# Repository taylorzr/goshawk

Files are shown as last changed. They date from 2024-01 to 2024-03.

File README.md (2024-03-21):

# goshawk

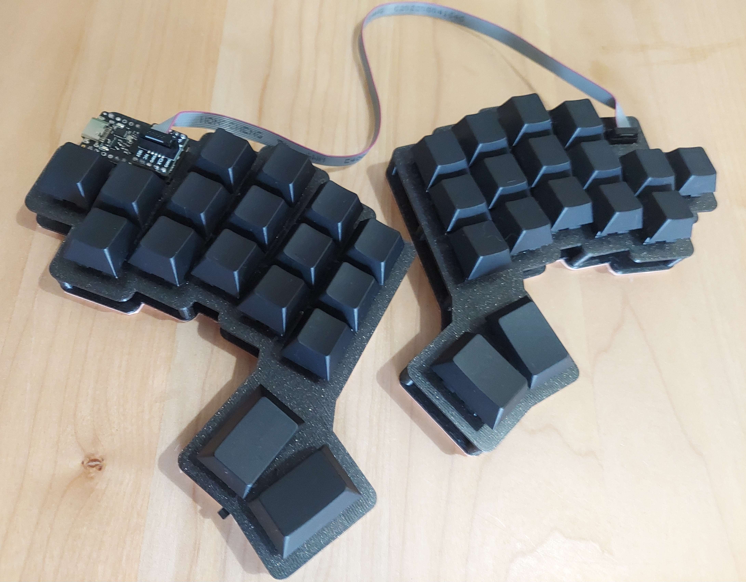
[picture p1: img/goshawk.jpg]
goshawk


wireless keyboard with distintive features rarely seen elsewhere

* split design, but only requires 1 controller/battery
* 8 physical rows mapped to 4 logical rows makes it easier to wire

splay and key layout inspired by [osprette](https://github.com/smores56/osprette) / [clog](https://github.com/smores56/clog-v2) and [lil chonky bois](https://github.com/sanderboer/chonkybois)

split inspired by [schrodinger](https://www.reddit.com/r/MechanicalKeyboards/comments/yrse5t/the_schrodinger_a_keyboard_thats_both_wired_and/)

## bom

| Syntax | Quantity | Link |
| --- | --- | ---- |
| nice-nano | 1 | https://nicekeyboards.com/nice-nano/#find-a-store |
| battery | 1 | 601230 |
| idc cable board | 2 | https://www.adafruit.com/product/2743 |
| idc cable | 1 | https://www.adafruit.com/product/5804 |
| power switch | 1 | https://www.amazon.com/dp/B09R3ZWBBC |

## build

see [build.md](./build.md)

## pinout

8 physical rows mapped to 4 logical rows. Rows 1-4 are left side, rows 5-8 are right side.

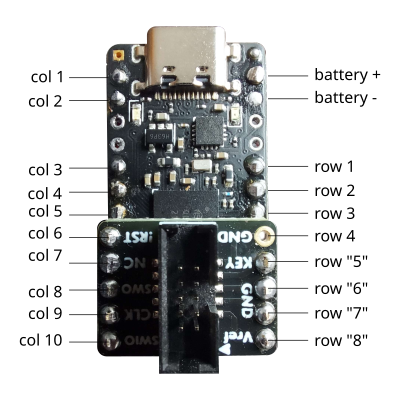
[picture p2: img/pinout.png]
pinout


## zmk config

https://github.com/taylorzr/zmk-config/tree/master/config/boards/shields/goshawk

## 3d model

https://cad.onshape.com/documents/b1a3d5d385ce946f6e9b2f83/w/2e8ce54f087bb732d581ef47/e/49486961fd79efcfe6401002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

## v1 -> v2

problems with v1
- pins are fragile
- fitting pins into bottom is finicky
  - i printed at same size, and then lightly drilled out the holes, but it was difficult to get
    consistent tension
- spacing between columns felt slightly too large
- pinky column drop was slightly too small

v2 changes
- added perimeter wall and slight chamfer
- m3 screws instead of pins
  - M3 x D5 x L4.0 (same as lil chonky bois)
  - https://www.amazon.com/uxcell-Knurled-Insert-Female-Embedding/dp/B09MCW7ZN5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
- adjusting column and pinky spacing
- no interior supports
  - with the perimeter wall, I don't feel like the top plate is too weak

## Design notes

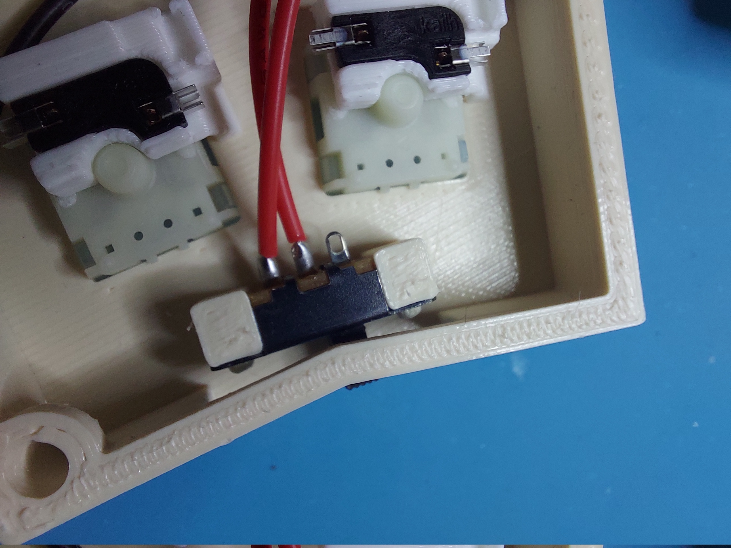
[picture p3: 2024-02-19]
img/power_switch.jpg

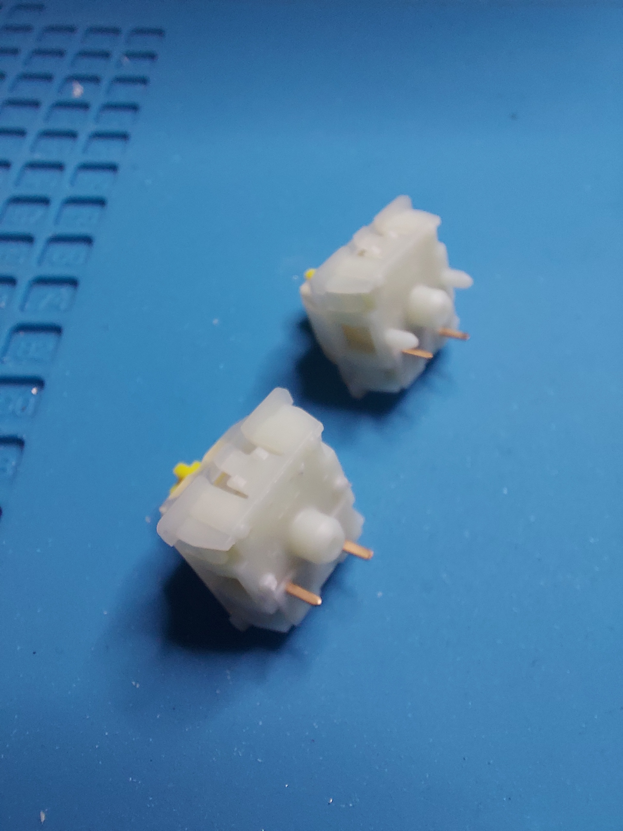
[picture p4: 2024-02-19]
img/remove_switch_pegs.jpg

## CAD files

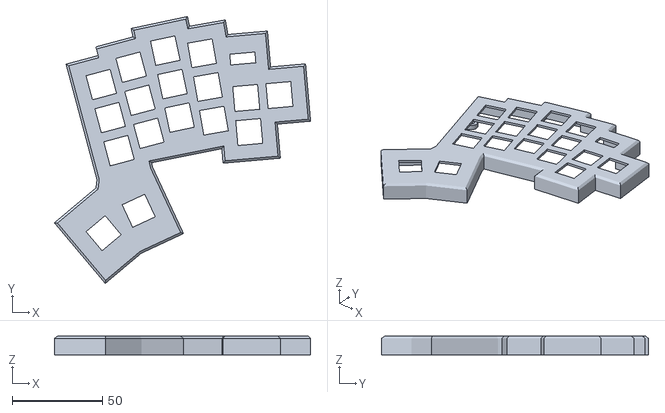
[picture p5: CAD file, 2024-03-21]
case/goshawk v2.1 - right.stl
142.4 x 148.3 x 10.4

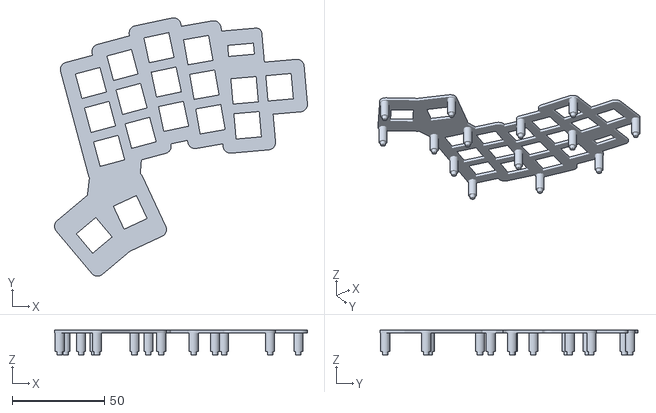
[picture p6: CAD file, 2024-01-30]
case/v1/right.stl
136.9 x 139.8 x 13.5

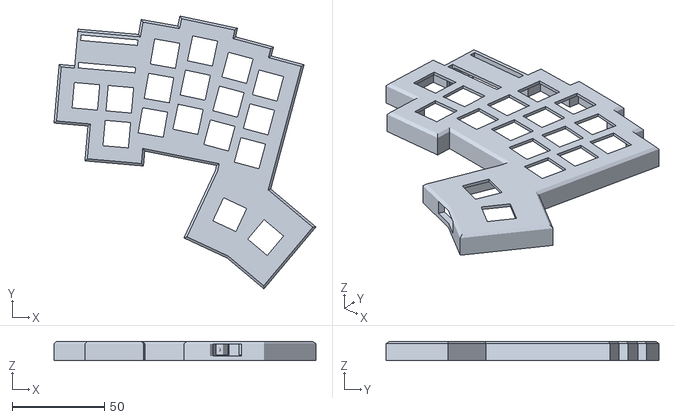
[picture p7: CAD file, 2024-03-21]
case/goshawk v2.1 - left.stl
142.4 x 148.3 x 10.4

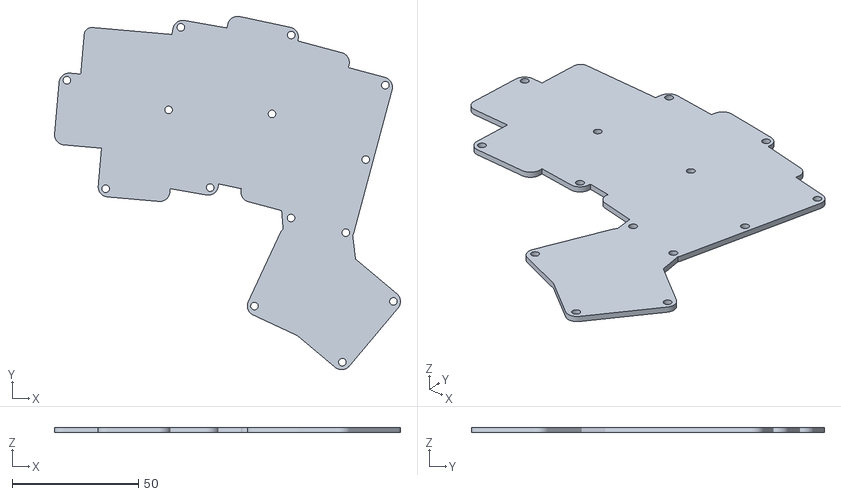
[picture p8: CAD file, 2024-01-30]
case/v1/left bottom.stl
136.9 x 139.8 x 2.00

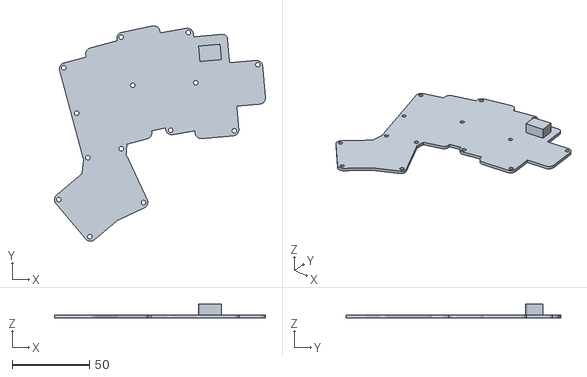
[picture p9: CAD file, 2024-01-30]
case/v1/right bottom.stl
136.9 x 139.8 x 9.00

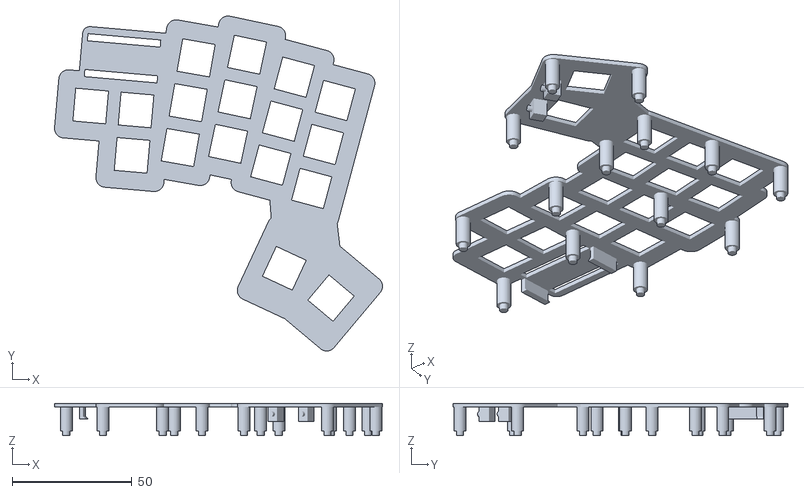
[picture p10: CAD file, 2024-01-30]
case/v1/left.stl
136.9 x 139.8 x 13.5

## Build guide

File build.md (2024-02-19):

# goshawk build guide

## Wiring left half

### icd board -> microcontroller

Solder headers onto the idc board. And then solder idc board to bottom of the microcontroller.

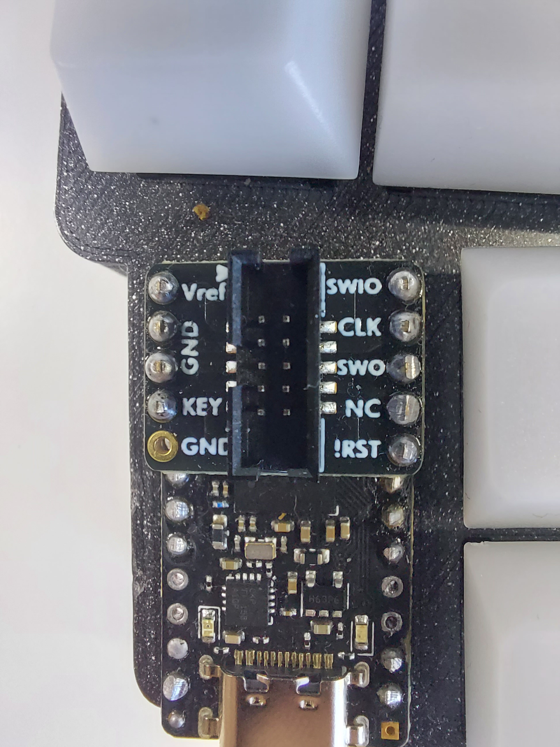
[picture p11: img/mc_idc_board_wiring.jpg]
mc_idc_board_wiring


The important part is the bottom left of the idc board should be left open. The pin is labeled GND on
the idc board. And on the microcontroller, this will be D18.

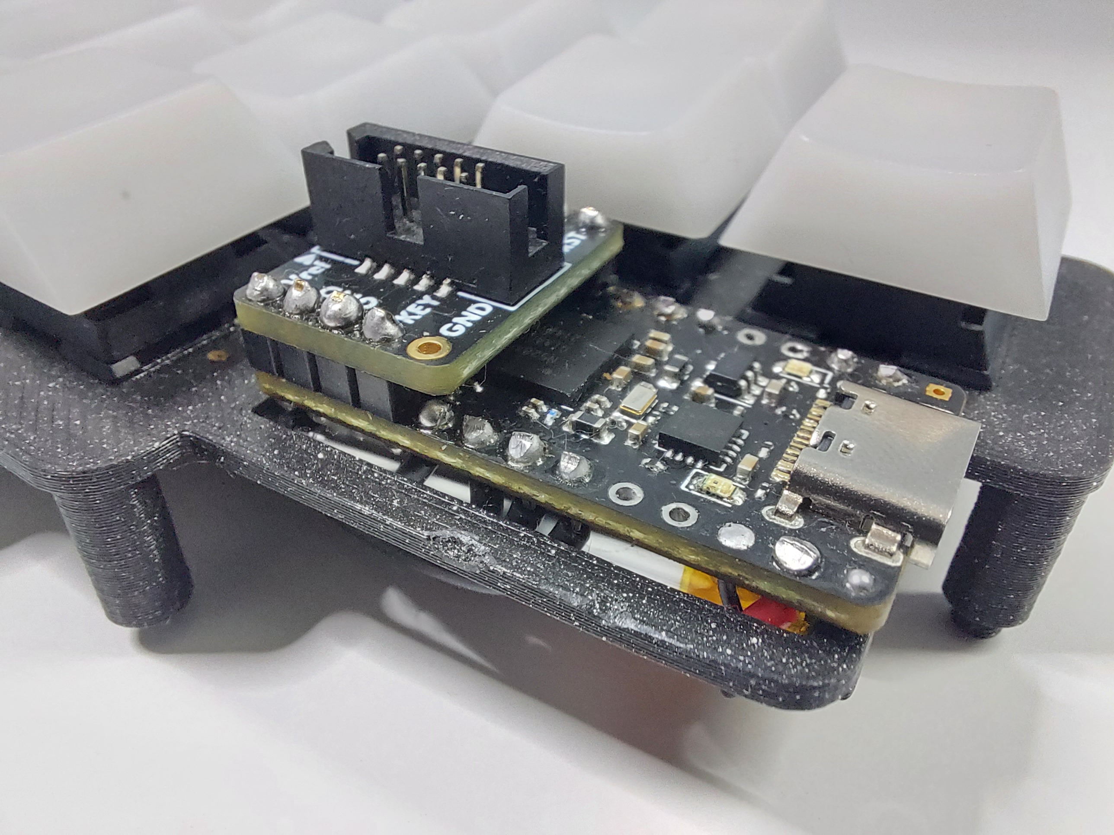
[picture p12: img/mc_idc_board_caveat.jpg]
mc_idc_board_caveat


### microcontroller wiring

Solder wires to the microcontroller. Make sure you leave them long enough to reach the rows,
columns, and power switch.

microcontroller_wiring

### microcontroller and battery installation

Pass microcontroller wiring through the case. Insert the battery, and solder the batteries black cable to microcontroller GND.

To attach the microcontroller to the case. I just use a command hook sticker. Cut it to size and slide it into place using a tweezer. Line up everything and squish.

mc_battery_install

### wire routing

Can run this however you want, but I've found you can get very clean wiring if you route the wires before soldering the matrix. This is a photo of the right side, but same process, route wires for columns, and for row 4.

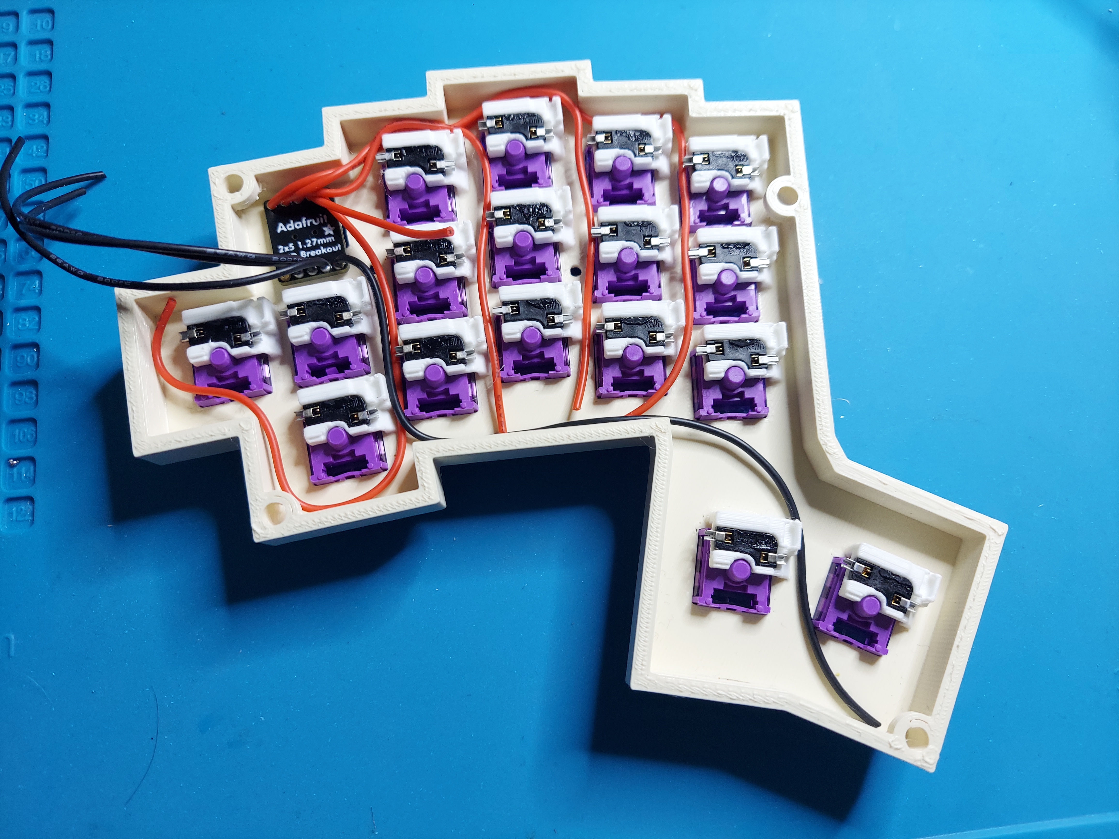
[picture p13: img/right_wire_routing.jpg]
right_wire_routing


### solder matrix

Solder colums first, then rows with diodes.

Batteries red cable, and the top right red cable get soldered to the power switch.

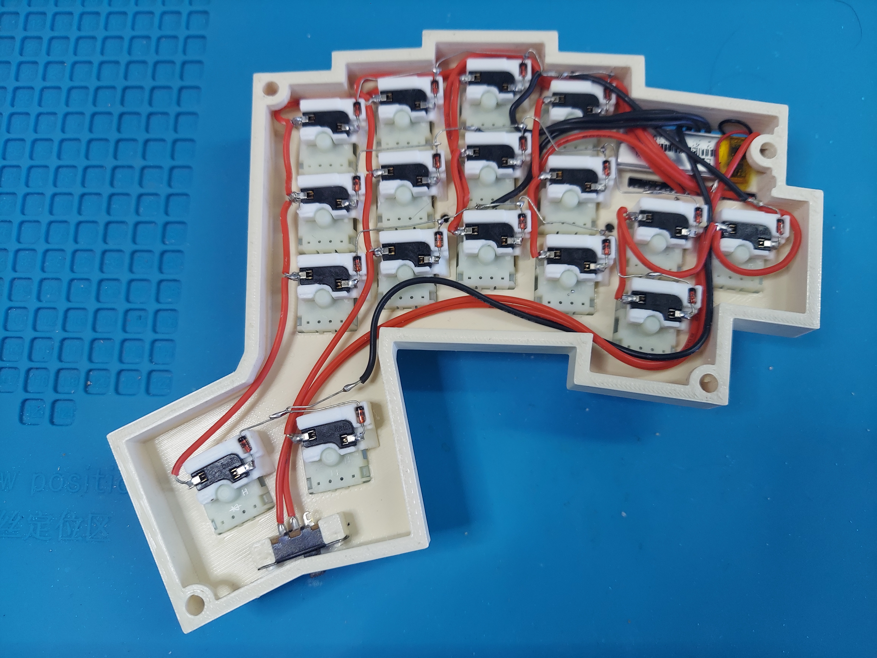
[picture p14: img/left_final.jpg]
left_final


## Wiring right half

### Wire idc board

Solder wires to idc board. Same as left half, make sure the wires are long enough to reach
everything.

idc_board

### Repeat process from the left side

1. route wires
2. solder matrix

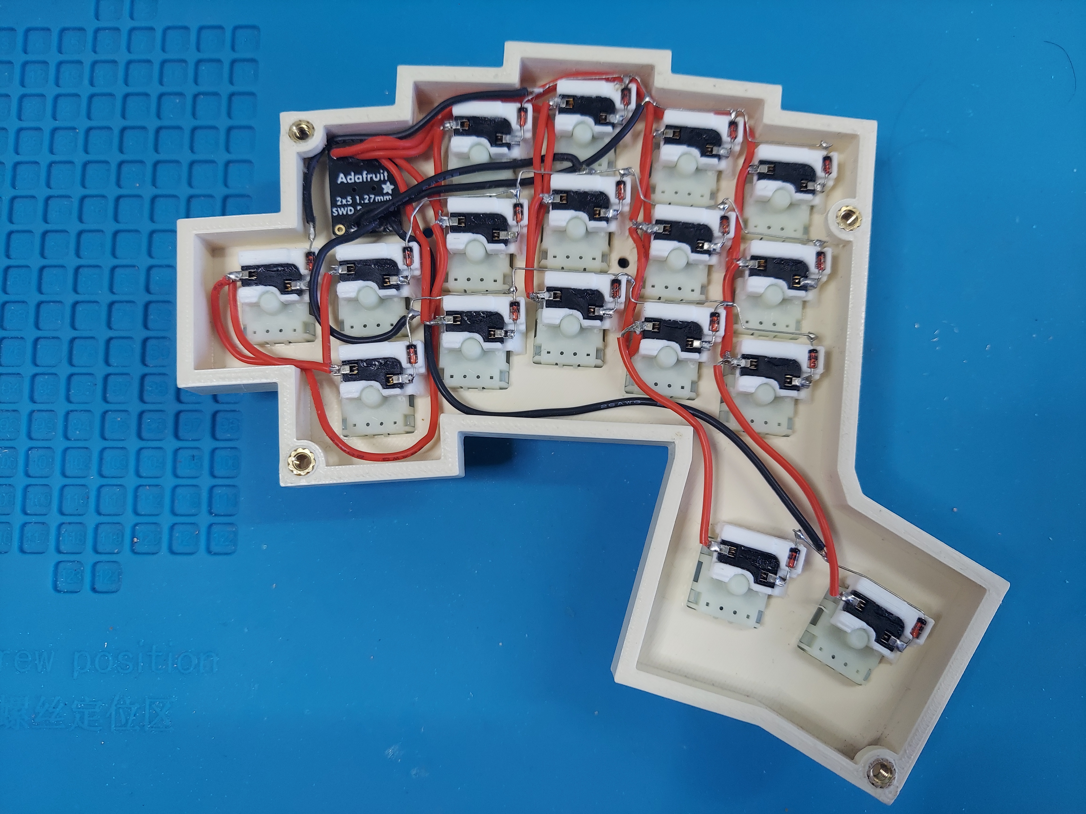
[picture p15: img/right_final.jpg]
right_final


## Optional

### hotswap sockets

This is optional but makes hotswap useful, and handwiring easier as it holds the diodes in place.

1. insert switches
2. insert hotswap sockets into holders
3. run a bead of superglue on the hotswap holder
4. press onto switch

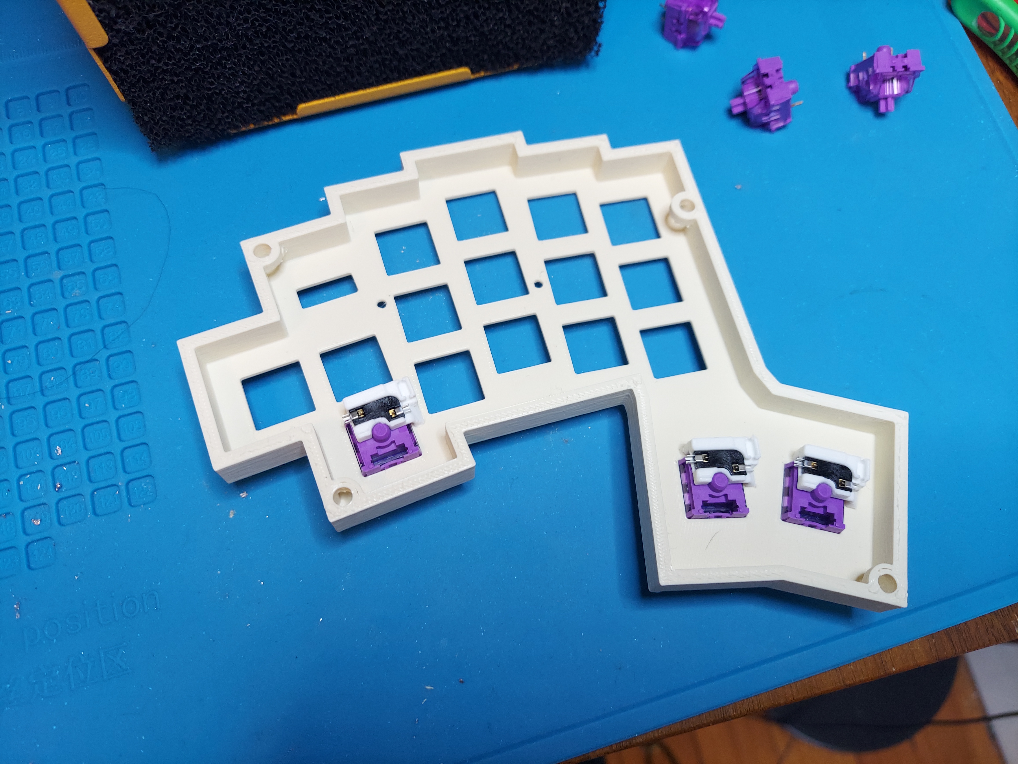
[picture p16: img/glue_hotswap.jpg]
glue_hotswap


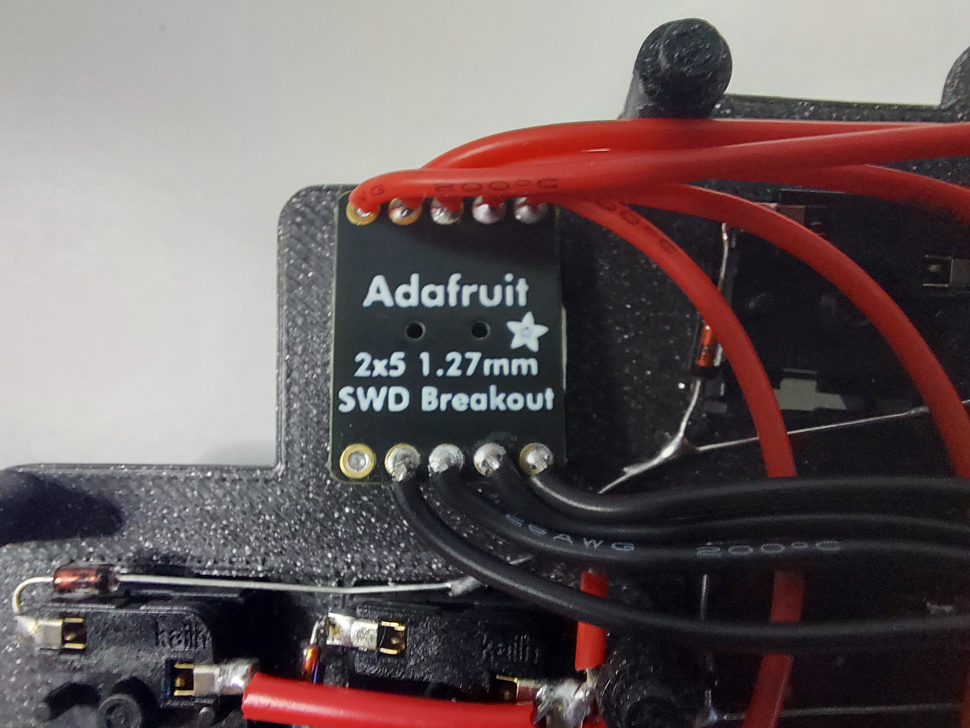
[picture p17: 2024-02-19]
img/idc_board_wiring.jpg

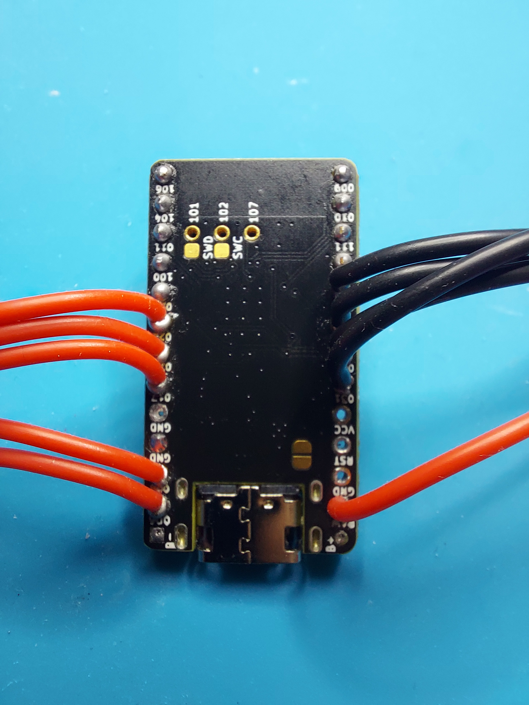
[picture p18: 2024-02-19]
img/microcontroller_wiring.jpg

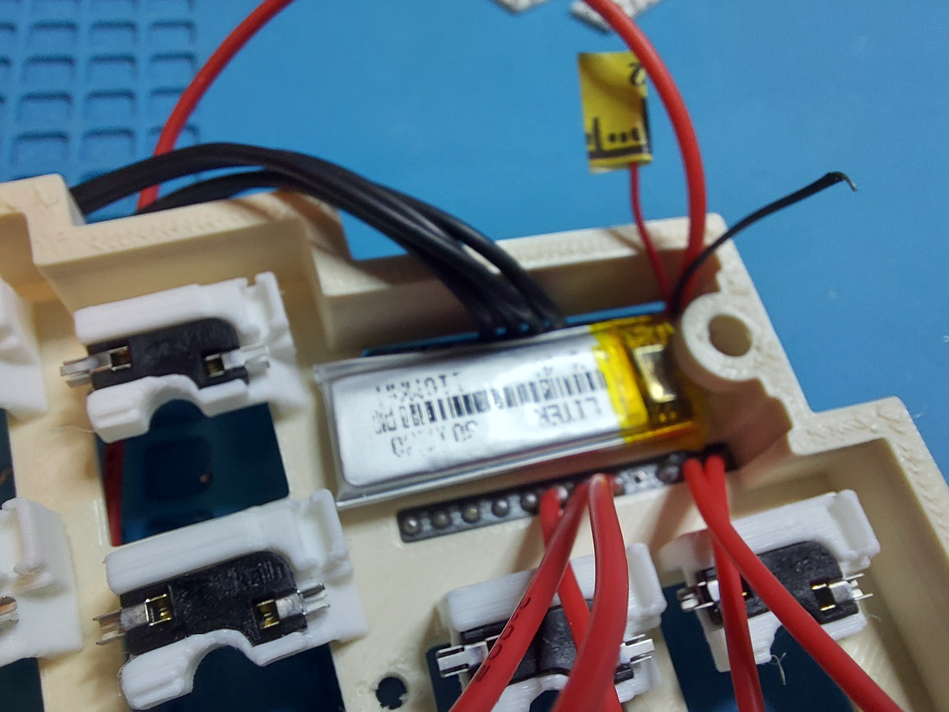
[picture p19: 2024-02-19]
img/mc_battery_install.jpg

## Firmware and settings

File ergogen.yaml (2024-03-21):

units:
  pinky_rotation: 10 # degrees rotation relative to zone rotation
  pinky_spread: 18.5
  
  ring_rotation: 5
  ring_spread: 19

  middle_rotation: 3
  middle_spread: 18.5

  index_rotation: 0
  index_spread: 18.5

  rounding: 0
  wall: 3
  hole_r: 1.25

  inner_rotation: 0
  inner_spread: 18.5

  choc_plate_thickness: 1.2
  mx_plate_thickness: 1.5

points:
  mirror:
    ref: thumb_right_home
    distance: 60
  rotate: 0
  key: # each key across all zones will have these properties
    bind: 5
    width: 1u
    height: 1u
    tags:
      1u: true
    footprints: # These footprints will be added for each of the points
      choc_hotswap:
        type: MX
        nets:
          to: "{{key_net}}"
          from: GND
        params:
          reverse: false
          hotswap: true
          # Don't show a model for this since 'choc' already loads the model
          model: false
          keycaps: false
      choc:
        type: MX
        anchor:
          rotate: 180
        nets:
          to: "{{key_net}}"
          from: GND
        params:
          keycaps: true
          reverse: false
  zones:
    matrix:
      key:
        tags:
          not_thumb: true
      rotate: -15
      rows:
        bottom.padding: 1u
        home.padding: 1u
        top.padding: 1u
      columns:
        outer:
          key:
            splay: pinky_rotation
            #tags: outer
          rows:
            bottom.skip: true
            home.key_net: P106
            home.key.tags: outer
            top.skip: true
        pinky:
          key:
            splay: pinky_rotation - pinky_rotation
            stagger: 0
            spread: pinky_spread
          rows:
            bottom.key_net: P104
            home.key_net: P102
            top.skip: true
        ring:
          key:
            splay: ring_rotation - pinky_rotation
            stagger: 8
            spread: ring_spread
          rows:
            bottom.key_net: P101
            home.key_net: P103
            top.key_net: P100
        middle:
          key:
            splay: middle_rotation - ring_rotation
            stagger: 5
            spread: middle_spread
          rows:
            bottom.key_net: P022
            home.key_net: P029
            top.key_net: P030
        index:
          key:
            splay: index_rotation - middle_rotation
            stagger: -5
            spread: index_spread
          rows:
            bottom.key_net: P031
            home.key_net: P004
            top.key_net: P005
        inner:
          key:
            splay: inner_rotation - index_rotation
            stagger: -5
            spread: inner_spread
          rows:
            bottom.key_net: P007
            home.key_net: P109
            top.key_net: P012
    thumb:
      key:
        tags:
          thumb: true
      anchor:
        ref: matrix_index_bottom
        shift: [ 0.75u, -1.75u]
      columns:
        left:
          key:
            splay: -10
            stagger: -5
            origin: [ -0.5u, -.75u ]
            key_net: P009
            rotate: 90
            width: 1.5u
        right:
          key:
            spread: 1.05u
            stagger: 0.15u # Move up by 0.25cy so a 1.5cy keycap lines up with the bottom
            splay: -15 # -25 degrees cumulative
            origin: [-1.1u, -0.75u] # Pivot at the lower left corner of a 1.5u choc key
            height: 1u
            width: 1.5u
            rotate: 90
            tags:
              15u: true
              1u: false
            key_net: P010
      rows:
        home:
          padding: 0
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
